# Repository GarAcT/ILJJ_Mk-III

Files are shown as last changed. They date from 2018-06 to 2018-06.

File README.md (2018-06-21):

# ILJJ Mk-III

コンパレータ付 8x8 CdSセル ダイナミックスキャン回路

## 仕様

3入力/8出力。
入力はスキャンを行う列 (2進数指定)、出力は半固定抵抗によって設定されたしきい値と比較した結果。

基板にはCdSセルは実装せず、外部にダイオードと共に回路図通りに配線されているものとし、基板の8ピンソケット2つと接続する。

ユニバーサル基板用の設計。

## 経緯

木更津高専情報工学科2年 実験実習II 文化祭での展示へ向けたボードゲーム制作

対戦型ペントミノを作ることになり、置かれたピースの判定にセンシングが必要になり制作した基板。
8x8に並べられたCdSセルをスキャンし、事前に設定したしきい値と比較して各マスにピースが置かれたか判定する。

ちなみにこれを稼働させるソフトウェアは [Joくん](https://github.com/nuller-jo) が担当。

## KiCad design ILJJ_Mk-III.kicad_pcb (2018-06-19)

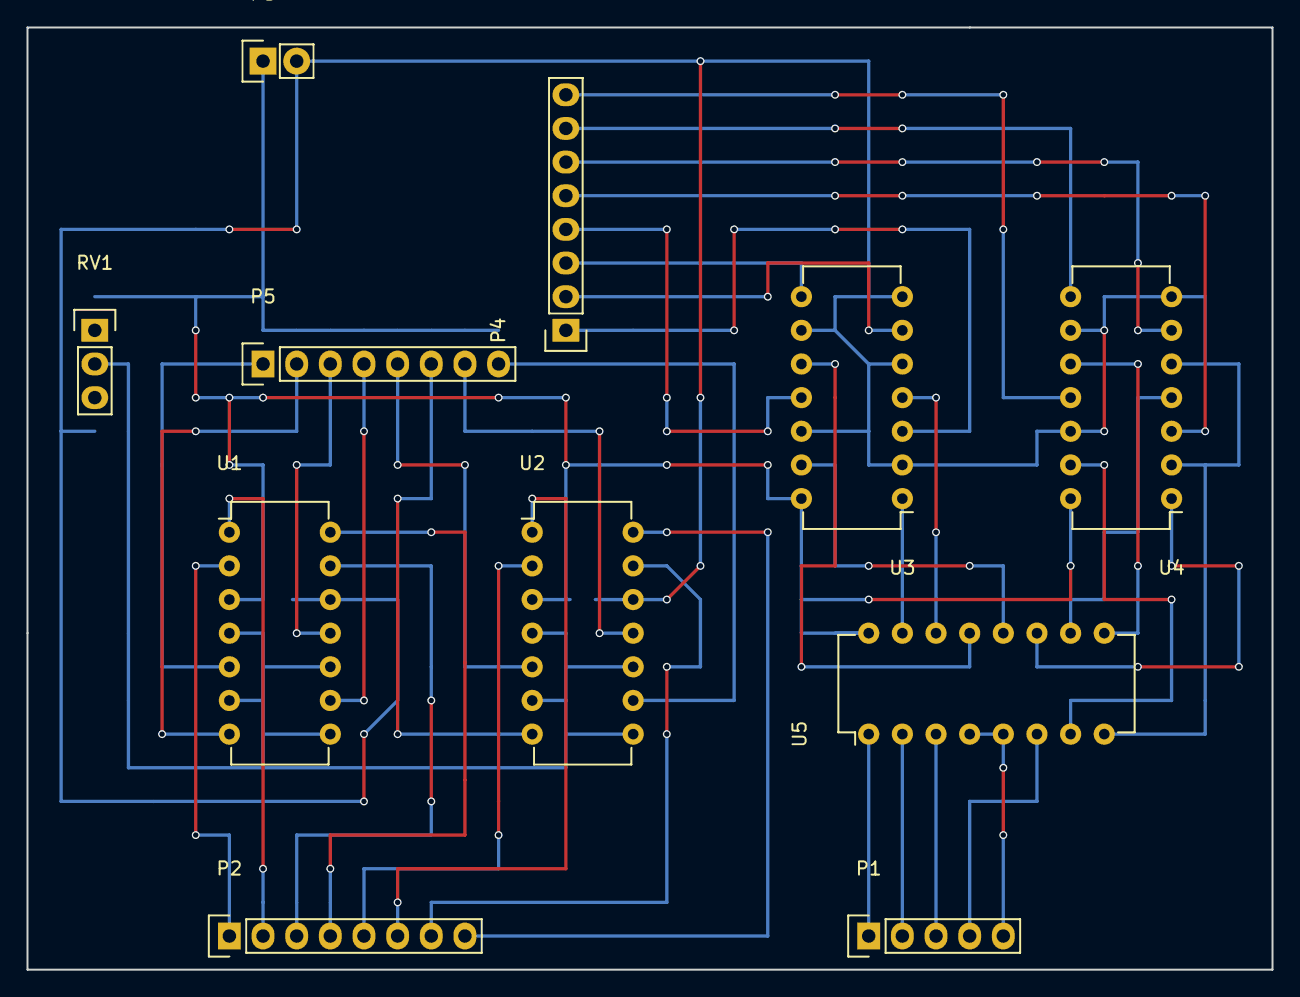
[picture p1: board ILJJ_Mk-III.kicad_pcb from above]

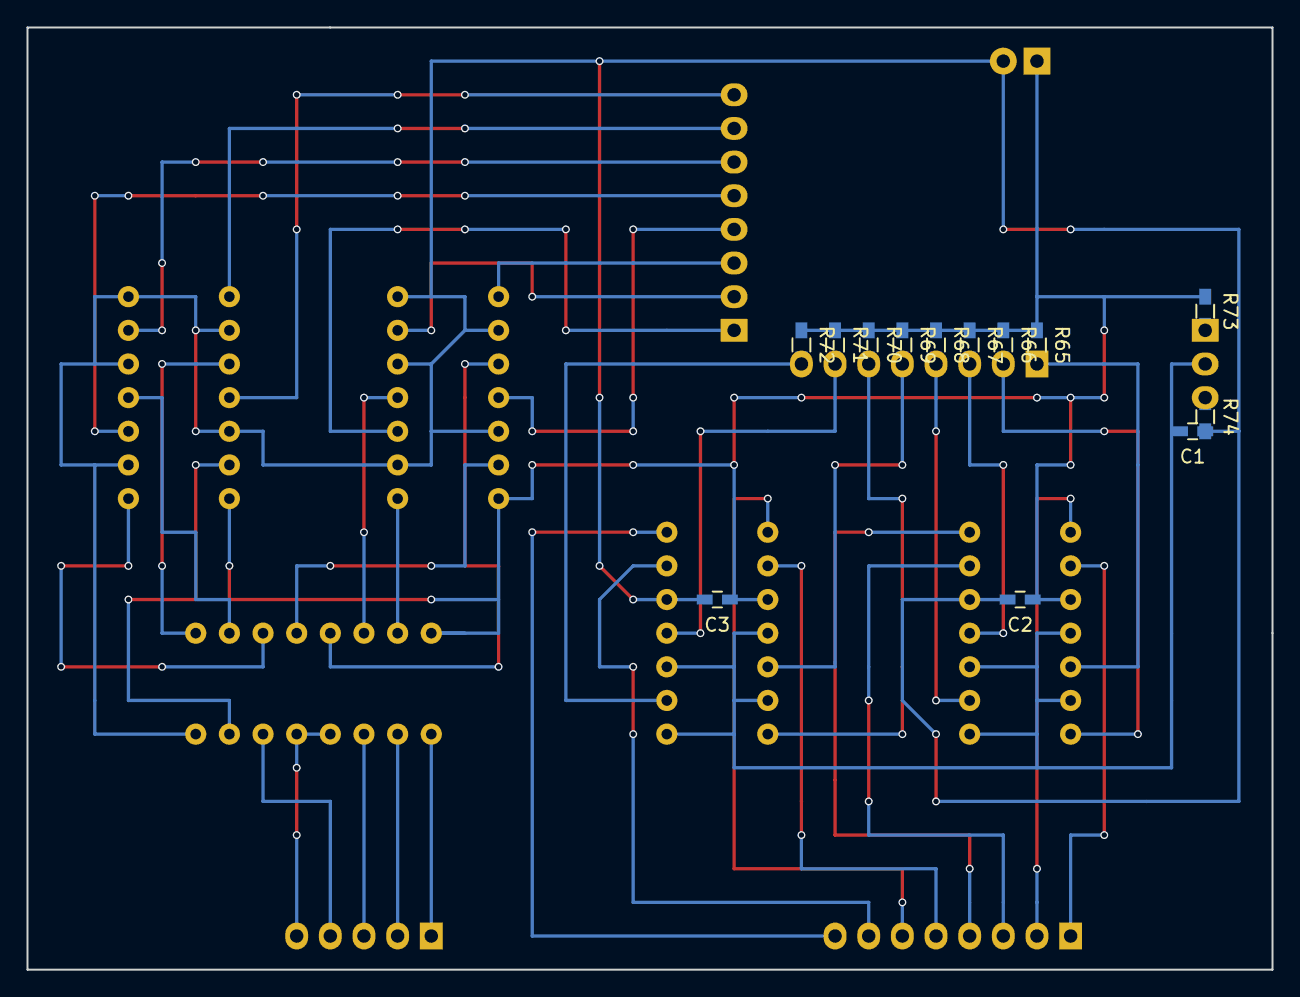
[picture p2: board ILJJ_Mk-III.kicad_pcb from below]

Board: 2 copper layers, 94.0 x 71.1 mm, 24 parts (13 on the bottom side), 42 nets.

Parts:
C1: 0.1uF; C_0603_HandSoldering
C2, C3: C; C_0603_HandSoldering
P1: CONN_01X05; Socket_Strip_Straight_1x05
P2, P4, P5: CONN_01X08; Socket_Strip_Straight_1x08
P3: CONN_01X02; Socket_Strip_Straight_1x02
R65, R66, R67, R68, R69, R70, R71, R72, R73, R74: R; R_0603_HandSoldering
RV1: POT; Pin_Header_Straight_1x03
U1, U2: LM339; DIP-14_W7.62mm
U3, U4: 74LS125; DIP-14_W7.62mm
U5: 74LS238; DIP-16_W7.62mm

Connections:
GND: C1.1, C2.2, C3.2, P3.2, R74.2, U1.12, U2.12, U3.2, U3.5, U3.7, U3.9, U3.12, U4.2, U4.5, U4.7, U4.9, U4.12, U5.8
unnamed: C1.2, RV1.2, U1.4, U1.6, U1.8, U1.10, U2.4, U2.6, U2.8, U2.10
unnamed: P1.1, U5.1
unnamed: P1.2, U5.2
unnamed: P1.3, U5.3
unnamed: P1.4, U5.6
unnamed: P1.5, U5.4, U5.5
unnamed: P2.1, U1.2
unnamed: P2.2, U1.1
unnamed: P2.3, U1.13
unnamed: P2.4, U1.14
unnamed: P2.5, U2.2
unnamed: P2.6, U2.1
unnamed: P2.7, U2.13
unnamed: P2.8, U2.14
unnamed: P4.1, U3.3
unnamed: P4.2, U3.6
unnamed: P4.3, U3.8
unnamed: P4.4, U3.11
unnamed: P4.5, U4.3
unnamed: P4.6, U4.6
unnamed: P4.7, U4.8
unnamed: P4.8, U4.11
unnamed: P5.1, R65.2, U1.5
unnamed: P5.2, R66.2, U1.7
unnamed: P5.3, R67.2, U1.11
unnamed: P5.4, R68.2, U1.9
unnamed: P5.5, R69.2, U2.5
unnamed: P5.6, R70.2, U2.7
unnamed: P5.7, R71.2, U2.11
unnamed: P5.8, R72.2, U2.9
unnamed: R73.2, RV1.1
unnamed: R74.1, RV1.3
unnamed: U3.1, U5.15
unnamed: U3.4, U5.14
unnamed: U3.10, U5.13
unnamed: U3.13, U5.12
unnamed: U4.1, U5.11
unnamed: U4.4, U5.10
unnamed: U4.10, U5.9
unnamed: U4.13, U5.7
VCC: C2.1, C3.1, P3.1, R65.1, R66.1, R67.1, R68.1, R69.1, R70.1, R71.1, R72.1, R73.1, U1.3, U2.3, U3.14, U4.14, U5.16
